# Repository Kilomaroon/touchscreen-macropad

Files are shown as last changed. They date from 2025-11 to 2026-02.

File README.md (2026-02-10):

# Happy Birthday!
We made you a little thing! Hope you enjoy it! We've been working on this for a bit and think you'll have a lot of fun tinkering with it!

To clarify: this is a touchscreen macropad we've made for you. It connects a little touchscreen display to an arduino - which sends your inputs over serial. You shouldn't need to mess with this side much though (unless you want to tweak the visuals) as the actual macro assignment is on the python end in the `computer-interface` folder.

# Setup
## Hardware Pinouts
You shouldn't need to rewire this - but just in case...
| RA8875 Pin  | Arduino Uno Pin
| ----- | --- |
|SCK|13|
|MISO|12|
|MOSI|11|
|CS|10|
|RST|9|
|INT|7|
|VIN|Vin|
|GND|GND|

## Arduino 
Install [Arduino IDE](https://www.arduino.cc/en/software/)
- Within the IDE, install the `Adafruit RA8875 v 1.4.4` and `Adafruit GFX` libraries and dependencies.
- Restart the IDE.
- Connect the Arduino to your PC and select it in the Arduino IDE's board selector.
- Press the little arrow in top left of IDE window to program the Arduino Uno.
- (If you are running Wayland, you may have trouble running the IDE---the easiest workaround is to run it in XWayland (ensure you have XWayland installed first))

### Modifying Button Layout
The buttons are laid out on the touchscreen in a rectangular layout. The number of columns and rows in the layout, as well as the margin between the buttons, can be configured by editing the `BUTTON_COLS`, `BUTTON_ROWS`, and `BUTTON_MARGIN` macros in the `touchscreen-macropad.ino` file. The button labels can be configured by editing the string array `numerals` in the same file.

## Computer
On the computer side, this sets up a systemd service to monitor your computer's serial connection and receive commands from the Arduino, then trigger keypress events using `evdev`. 

It also sets up a few udev rules to automatically run/stop the service when the macropad is connected/disconnected, and to make a symlink so the service doesn't have to worry about which serial port the Arduino is connected to. (There's also an optional additional udev rule that will send a desktop notification when the macropad is plugged in, mostly because I sort of set that up by accident when trying to figure out how to do the systemd service.)

### Installation
Ensure you have the system packages `python3-evdev` ([documentation](https://python-evdev.readthedocs.io/en/latest/)) and `python3-serial` ([documentation](https://www.pyserial.org/docs)) installed.
* (they should already be installed on Mint [NO THEY ARE NOT] [INSTALL THEM])
* On Arch these can be found as [`python-evdev`](https://archlinux.org/packages/extra/x86_64/python-evdev/) and [`python-pyserial`](https://archlinux.org/packages/extra/any/python-pyserial/)
* After installation, you may need to reboot in order for the systemd service to run properly (you may see error messages about missing dependencies until you do this).

From the `computer-interface` directory, make the `setup.sh` file executable using
```bash
chmod +x setup.sh
```

Then run it (sudo required) using
```bash
sudo ./setup.sh
```

Make sure `/usr/local/bin/touch-macropad-service.py` is readable by your user, if it is not already.
```bash
sudo chmod 644 /usr/local/bin/touch-macropad-service.py
```

If you make any changes to the files after the initial installation, you may have to run 
```bash
sudo udevadm --reload
```
to reload your udev rules, or
```bash
sudo systemctl daemon-reload
```
to reload your systemd manager config in order for them to take effect.

### Configuring Functions
To configure the functions of each button, edit the `key_sequences` dict in `touch-macropad-service.py`. You can configure a keypress or combination of keypresses to be sent when each button is pressed (+) or released (-). The default setup is as follows:

| Button | Press  | Release |
| --- | -----  | --- |
| 0 | CTRL-S | \<nothing\> |
| 1 | CTRL-C | \<nothing\> |
| 2 | CTRL-V | \<nothing\> |
| 3 | CTRL-C | CTRL-V |

### Further Configuration
If you'd like to screw further with this side of things, much of it was informed by/adapted from the examples in the `PySerial` docs, available [here](https://www.pyserial.org/docs/linux-serial). The general structure is that `98-touch-macropad.rules` contains the udev rules, one of which establishes a dependency on `touch-macropad-service`, which is defined by the `touch-macropad-service.conf`, `touch-macropad-service.py`, and `touch-macropad-service.service` files. 

If you are making changes, you may find it useful to monitor the systemd logs for `touch-macropad-service` using
```bash
journalctl -f -u touch-macropad-service
```

### (Optional) Device Connection Notifications
If desired, the udev configuration can be modified to send a desktop notification when the device is connected. To do so, uncomment the last line in `computer-interface/98-touch-macropad.rules` and copy `computer-interface/arduino-connected.sh` to `/usr/local/bin/arduino-connected.sh` with:
```bash
sudo cp computer-interface/arduino-connected.sh /usr/local/bin/arduino-connected.sh
```

# Commit Message Glossary
| Word  | Definition
| ----- | --- |
| **Evert** | *Verb, transitive.* To turn inside out or outwards. From Late Latin *ēvertere* (“to turn (an item of clothing) inside out”), Latin *ēvertere*, present active infinitive of *ēvertō* (“to turn upside down; to overturn; to reverse”), from *ē-* (variant of *ex-* (prefix meaning ‘out, away’)) + *vertō* (“to reverse; to revolve, turn; to turn around”) (ultimately from Proto-Indo-European **wert-* (“to rotate, turn”)) [1]. |

### References
[1] Wiktionary contributors, “evert,” Wiktionary. Accessed: Nov. 11, 2025. [Online]. Available: https://en.wiktionary.org/w/index.php?title=evert&oldid=85391271

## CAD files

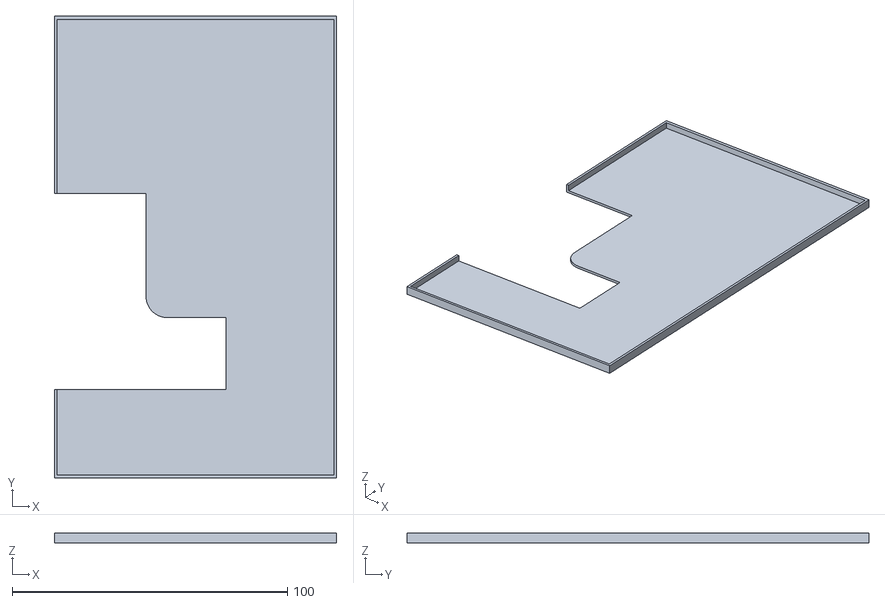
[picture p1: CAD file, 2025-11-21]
case/rear-plate.stl
102.4 x 167.7 x 3.50

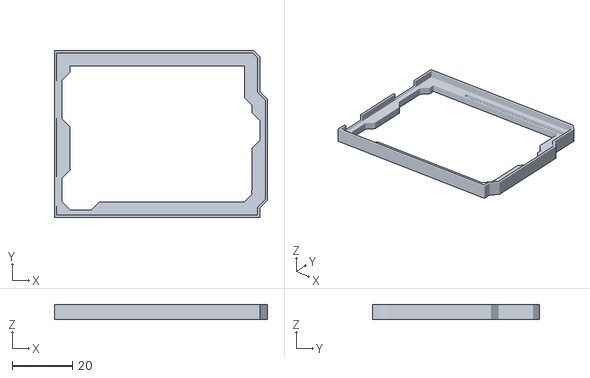
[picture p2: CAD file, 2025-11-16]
case/Arduino_Bumper_0005.stl
70.5 x 55.2 x 5.08

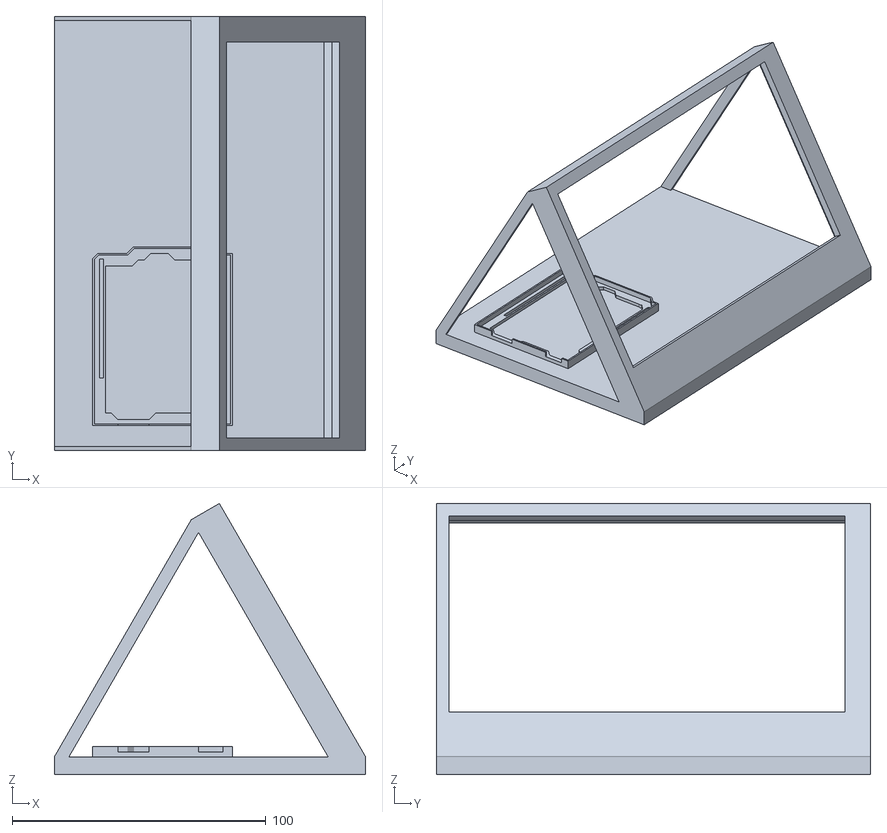
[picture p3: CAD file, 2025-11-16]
case/case.stl
122.6 x 171.0 x 106.8

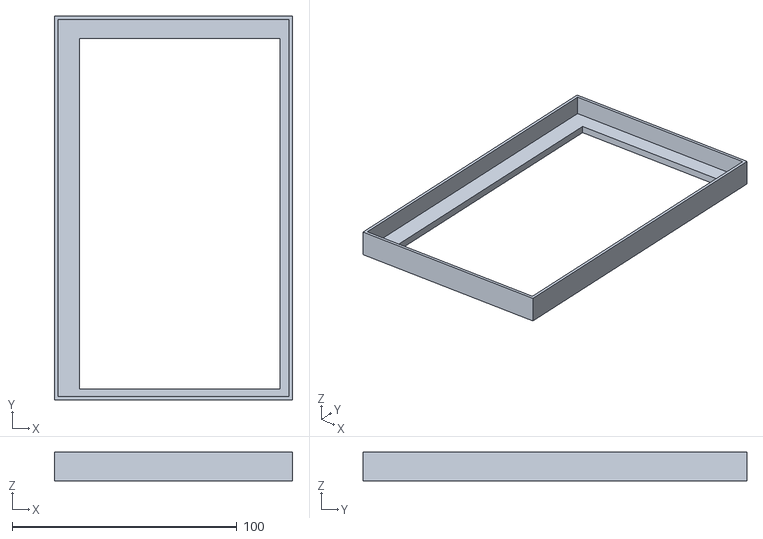
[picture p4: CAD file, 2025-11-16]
case/adafruit-2354-7in-tft-touchscreen-front-bezel.stl
106.0 x 171.0 x 12.8

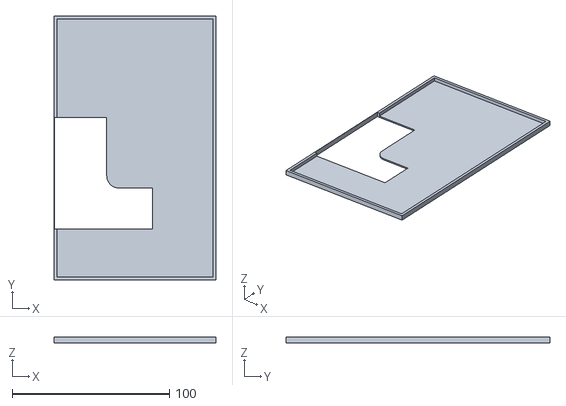
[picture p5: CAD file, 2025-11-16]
case/adafruit-2354-7in-tft-touchscreen-rear-bezel.stl
103.0 x 168.0 x 3.50

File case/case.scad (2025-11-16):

module frontBezel() {
    translate([3,3,3.8])
        import("adafruit-2354-7in-tft-touchscreen-front-bezel.stl");
}

module arduino() {
    import("Arduino_Bumper_0005.stl");
}

difference() {
union() {
    translate([0.385,0,0])
    union(){
        translate([-5,0,15])
        rotate([0,-120,0])
            frontBezel();

        translate([-5,0,7])
        rotate([0,-120,0])
        translate([-2.5,0,-4])
            cube([10,171,12.8]);
    }
    translate([-122.6,0,0])
        cube([122.6,171,7]);
    
    translate([-64.37,0,97.9])
    rotate([0,-150,0])
        cube([5,1.5,110]);
    
    translate([-64.37,169.5,97.9])
    rotate([0,-150,0])
        cube([5,1.5,110]);
    
    translate([-80,45,6])
    rotate([0,0,90])
        arduino();
}

translate([0,-5,0])
    cube([10,200,10]);

translate([-132.6,-5,0])
    cube([10,200,20]);
}

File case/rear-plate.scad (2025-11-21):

module original() {
    translate([1.5,1.5,-5.5])
    import("adafruit-2354-7in-tft-touchscreen-rear-bezel.stl");
}
difference() {
    original();
    translate([1.3,1.3,1])
        cube([100.4,165.4,5]);
    
    translate([0,-0.1,0])
        cube([120,0.4,5]);
    translate([-0.1,0,0])
        cube([0.4,200,5]);
    translate([102.7,0,0])
        cube([0.4,200,5]);
    translate([167.8,0,0])
        cube([120,0.4,5]);
}

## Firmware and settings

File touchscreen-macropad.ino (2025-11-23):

#include <SPI.h>
#include "Adafruit_GFX.h"
#include "Adafruit_RA8875.h"

// Library only supports hardware SPI at this time
// Connect SCLK to UNO Digital #13 (Hardware SPI clock)
// Connect MISO to UNO Digital #12 (Hardware SPI MISO)
// Connect MOSI to UNO Digital #11 (Hardware SPI MOSI)
#define RA8875_INT 7
#define RA8875_CS 10
#define RA8875_RESET 9

#define SCREEN_WIDTH 800
#define SCREEN_HEIGHT 480
#define SCREEN_MARGIN 50

#define BUTTON_COLS 3
#define BUTTON_ROWS 2
#define BUTTON_MARGIN 50

#define BUTTON_THRESHOLD 6

const int button_width = (SCREEN_WIDTH - 2*SCREEN_MARGIN - BUTTON_MARGIN * (BUTTON_COLS - 1)) / BUTTON_COLS;
const int button_height = (SCREEN_HEIGHT - 2*SCREEN_MARGIN - BUTTON_MARGIN * (BUTTON_ROWS - 1)) / BUTTON_ROWS;
int button_coords[BUTTON_ROWS][BUTTON_COLS][2];

// All the UI variables
const String numerals[] = {"I", "II", "III", "IV", "V", "VI", "VII", "VIII", "IX", "X", "XI", "XII"};
int button_radius = 20;
int button_colour = 0xf529;
int fg_colour = button_colour;
int bg_colour = RA8875_BLACK;
int text_size = 3;

int button_states[BUTTON_ROWS][BUTTON_COLS];
unsigned long last_touch[BUTTON_ROWS][BUTTON_COLS];


Adafruit_RA8875 tft = Adafruit_RA8875(RA8875_CS, RA8875_RESET);
uint16_t tx, ty, mx, my, x, y; // x and y are the actual coords you want here

void setup() {
  Serial.begin(19200);
  Serial.println("RA8875 start");

  /* Initialize the display using 'RA8875_480x80', 'RA8875_480x128', 'RA8875_480x272' or 'RA8875_800x480' */
  if (!tft.begin(RA8875_800x480)) {
    Serial.println("RA8875 Not Found!");
    while (1);
  }

  Serial.println("Found RA8875");

  // these are the four lines you need to make this thing turn on
  tft.displayOn(true);
  tft.GPIOX(true);      // Enable TFT - display enable tied to GPIOX
  tft.PWM1config(true, RA8875_PWM_CLK_DIV1024); // PWM output for backlight
  tft.PWM1out(255);

  tft.fillScreen(RA8875_BLACK);
  init_buttons();

  pinMode(RA8875_INT, INPUT);
  digitalWrite(RA8875_INT, HIGH);
  
  mx = tft.width();
  my = tft.height();

  tft.touchEnable(true);

  Serial.print("Status: "); Serial.println(tft.readStatus(), HEX);
  Serial.println("Waiting for touch events ...");
}

void loop() {
  poll_buttons();
}


/**
 * Calculate button coords & draw to screen
 * 
 * For each button, calculate the x & y coords for the top left corner, then draw a white rectangle
 * to represent the button onscreen.
 */
void init_buttons() {
  for (int i = 0; i < BUTTON_ROWS; i++) {
    int button_y = SCREEN_MARGIN + i*(BUTTON_MARGIN+button_height);
    for (int j = 0; j < BUTTON_COLS; j++) {
      int button_x = SCREEN_MARGIN + j*(BUTTON_MARGIN+button_width);
      button_coords[i][j][0] = button_x;
      button_coords[i][j][1] = button_y;

      draw_button(i, j, false);
      last_touch[i][j] = millis();
    }
  }
}

void button_press(int i, int j) {
  Serial.println(String(i*BUTTON_COLS + j) + "+");
  draw_button(i, j, true);
}

void button_unpress(int i, int j) {
  Serial.println(String(i*BUTTON_COLS + j)+ "-");
  draw_button(i, j, false);
}

/**
 * Draws a single button at position i and j
 * 
 * press_state is either currently being pressed (true), or before/after a press (false)
 */
void draw_button(int i, int j, bool press_state) {

  if (press_state == true) {
    fg_colour = RA8875_BLACK;
    bg_colour = button_colour;
  } else {
    fg_colour = button_colour;
    bg_colour = RA8875_BLACK;
  }

  tft.fillRoundRect(button_coords[i][j][0], button_coords[i][j][1], button_width, button_height, button_radius, bg_colour);
  
  for (int p = 0; p < 5; p++) {
    tft.drawRoundRect((button_coords[i][j][0]+p), (button_coords[i][j][1]+p), button_width-(p*2), button_height-(p*2), button_radius, button_colour); //Make border around button (no, there was no better way - I checked)
  }
  
  tft.textMode();
  tft.textEnlarge(text_size);
  // Sets cursor to the middle of button, the way enlarging works is that the text size turns into 8 pixels * (scaling_factor + 1)
  tft.textSetCursor((button_coords[i][j][0]+(button_width-(8*(text_size+1)*numerals[i * BUTTON_COLS + j].length()))/2), (button_coords[i][j][1]+(button_height-(16*(text_size+1)))/2)); 
  tft.textColor(fg_colour, bg_colour); 
  
  if (i * BUTTON_COLS + j < sizeof(numerals)/sizeof(String)){
    tft.print(numerals[i * BUTTON_COLS + j]);
  } else {tft.print(numerals[0]);}
   
  tft.graphicsMode();
}

void poll_buttons() {
  
  // if touch report available, read & handle
  if (!digitalRead(RA8875_INT)) {
    if (tft.touched()) {
      tft.touchRead(&tx, &ty);
      x = map(tx, 50, 970, 0, mx);
      y = map(ty, 140, 930, 0, my);
      
      // check if touch is on any button
      for (int i = 0; i < BUTTON_ROWS; i++) {
        for (int j = 0; j < BUTTON_COLS; j++) {
          if (button_coords[i][j][0] <= x && x <= (button_coords[i][j][0] + button_width) && button_coords[i][j][1] <= y && y <= (button_coords[i][j][1] + button_height)) {
            // if button touched, increment state counter; BUTTON_THRESHOLD reports trigger button
            if (button_states[i][j] == BUTTON_THRESHOLD) {
              button_press(i, j);
              button_states[i][j]++;
            } else if (button_states[i][j] < BUTTON_THRESHOLD) {
              button_states[i][j]++;
            }
            last_touch[i][j] = millis();
          } else if ((millis() - last_touch[i][j]) > 100) {
              // if button pressed, unpress
            if (button_states[i][j] > BUTTON_THRESHOLD) {
              button_unpress(i,j);
            }
            // reset button counters regardless
            button_states[i][j] = 0;
            last_touch[i][j] = millis();
          }
        }
      }
    }

  // if no touch report, check timeout and unpress buttons if elapsed - kind of a makeshift watchdog
  } else {
    for (int i = 0; i < BUTTON_ROWS; i++) {
      for (int j = 0; j < BUTTON_COLS; j++) {
        if ((millis() - last_touch[i][j]) > 100) {
          // if button pressed, unpress
          if (button_states[i][j] > BUTTON_THRESHOLD) {
            button_unpress(i,j);
          }
          // reset button counters regardless
          button_states[i][j] = 0;
          last_touch[i][j] = millis();
        }
      }
    }

  }
}

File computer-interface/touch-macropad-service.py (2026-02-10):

# /usr/local/bin/touch-macropad-service.py
from evdev import UInput, ecodes
#import evdev
import re
import serial
import time
import logging
import signal
import sys
from pathlib import Path

key_sequences = {
    "0+": [ecodes.KEY_LEFTCTRL, ecodes.KEY_S],
    "1+": [ecodes.KEY_LEFTCTRL, ecodes.KEY_C],
    "2+": [ecodes.KEY_LEFTCTRL, ecodes.KEY_V],
    "3+": [ecodes.KEY_LEFTCTRL, ecodes.KEY_C],
    "0-": [],
    "1-": [],
    "2-": [],
    "3-": [ecodes.KEY_LEFTCTRL, ecodes.KEY_V]
}


class SerialService:
    def __init__(self, config_file='/etc/touch-macropad-service.conf'):
        self.config_file = config_file
        self.running = False
        self.serial = None
        self.ui = UInput()
        self.packetMatch = re.compile("^(\\d+)[\\+\\-]$")
        self.setup_logging()
        
    def setup_logging(self):
        """Setup logging for systemd"""
        logging.basicConfig(
            level=logging.INFO,
            format='%(asctime)s - %(levelname)s - %(message)s'
        )
        self.logger = logging.getLogger(__name__)
        
    def load_config(self):
        """Load configuration"""
        config = {
            'port': '/dev/touchscreenmacropad',
            'baudrate': 19200,
            'timeout': 1,
            'retry_interval': 5
        }
        
        try:
            if Path(self.config_file).exists():
                with open(self.config_file, 'r') as f:
                    for line in f:
                        if '=' in line and not line.strip().startswith('#'):
                            key, value = line.strip().split('=', 1)
                            if key in config:
                                if key == 'baudrate' or key == 'timeout' or key == 'retry_interval':
                                    config[key] = int(value)
                                else:
                                    config[key] = value
        except Exception as e:
            self.logger.error(f"Error loading config: {e}")
            
        return config
        
    def connect_serial(self, config):
        """Connect to serial device with retry"""
        while self.running:
            try:
                self.logger.info(f"Attempting to connect to {config['port']}")
                self.serial = serial.Serial(
                    port=config['port'],
                    baudrate=config['baudrate'],
                    timeout=config['timeout']
                )
                self.logger.info(f"Connected to {config['port']}")
                return True
                
            except Exception as e:
                self.logger.error(f"Connection failed: {e}")
                time.sleep(config['retry_interval'])
                
        return False
        
    def process_data(self, data):
        """Process received data"""
        # Override this method in subclasses
        try:
            data_string = data.decode('utf-8', errors='ignore').strip()
            packet = self.packetMatch.match(data_string)
            if packet:
                self.logger.info(f"Received: {data_string}")
                for k in key_sequences[data_string]:
                    self.ui.write(ecodes.EV_KEY, k, 1)
                self.ui.syn()

                for k in key_sequences[data_string]:
                    self.ui.write(ecodes.EV_KEY, k, 0)
                self.ui.syn()
            else:
                self.logger.error(f"Invalid data received from device: {data_string}")
        except Exception as e:
            self.logger.error(f"Error reading from device: {e}")
        
    def run(self):
        """Main service loop"""
        self.running = True
        config = self.load_config()
        
        self.logger.info("Serial service starting")

        # devices = [evdev.InputDevice(path) for path in evdev.list_devices()]
        # for device in devices:
        #     self.logger.info(device.name)
        
        if not self.connect_serial(config):
            self.logger.error("Failed to establish serial connection")
            return 1
            
        try:
            while self.running:
                if self.serial.in_waiting:
                    data = self.serial.readline()
                    self.process_data(data)
                    
                time.sleep(0.01)  # Small delay to prevent CPU spinning
                
        except Exception as e:
            self.logger.error(f"Service error: {e}")
            return 0
        finally:
            self.cleanup()
            
        self.logger.info("Serial service stopped")
        return 0
        
    def cleanup(self):
        """Cleanup resources"""
        if self.serial:
            self.serial.close()
            self.ui.close()
            
    def signal_handler(self, signum, frame):
        """Handle shutdown signals"""
        self.logger.info(f"Received signal {signum}")
        self.running = False

if __name__ == "__main__":
    service = SerialService()
    
    # Handle signals
    signal.signal(signal.SIGTERM, service.signal_handler)
    signal.signal(signal.SIGINT, service.signal_handler)
    
    # Run service
    sys.exit(service.run())

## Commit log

2025-11-05 update pinouts and arduino code
2025-11-11 set up button display (beautiful white boxes), touch -> button conversion, fired first shot in war with spurious touch reports from screen
2025-11-11 buttons now change colour when pressed
2025-11-11 everted program flow to avoid gating everything behind goddamn touch interrupts, adopted watchdog timer (ha ha) to handle button-unpress
    [arduino-ide-files.ino]
2025-11-12 found legitimate excuse to use goto, no velociraptors as yet, xkcd lied
2025-11-12 switched to fugly implementation of button-by-button watchdog timeouts
2025-11-14 calculate button IDs programmatically instead of having an array storing just the numbers 123456
2025-11-16 frankensteined a case together
    [Arduino_Bumper_0005.stl, adafruit-2354-7in-tft-touchscreen-front-bezel.stl, adafruit-2354-7in-tft-touchscreen-rear-bezel.stl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]
2025-11-21 as Victor, I have been betrayed by my own creation - updated case design
    [rear-plate.scad, rear-plate.stl]
2025-11-23 install script no longer replaces half the file with your username, fixed pinout
    [touchscreen-macropad.ino]
2026-02-10 spring cleaning. compatibility with arch linux + non matching user/group situations. fancier bash script.
